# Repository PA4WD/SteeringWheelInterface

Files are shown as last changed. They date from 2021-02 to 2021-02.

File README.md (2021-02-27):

Steering wheel interface for Nissan Note 2006  to Kenwood NEC remote input

orginal wiring  in the car

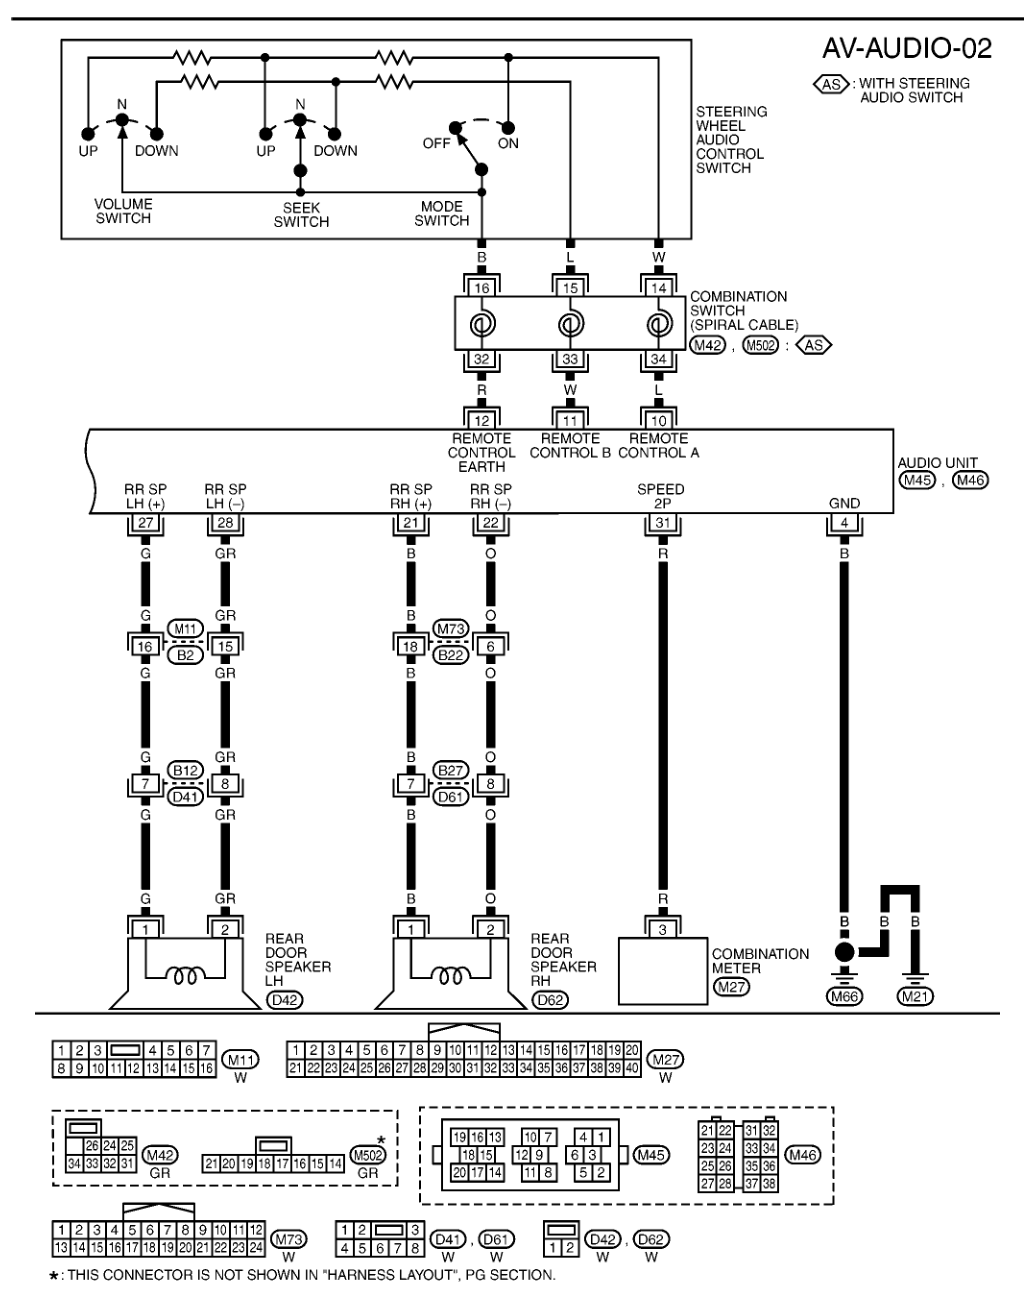
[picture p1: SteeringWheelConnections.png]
Steering wheel to radio


Resistor values from the steering wheel buttons

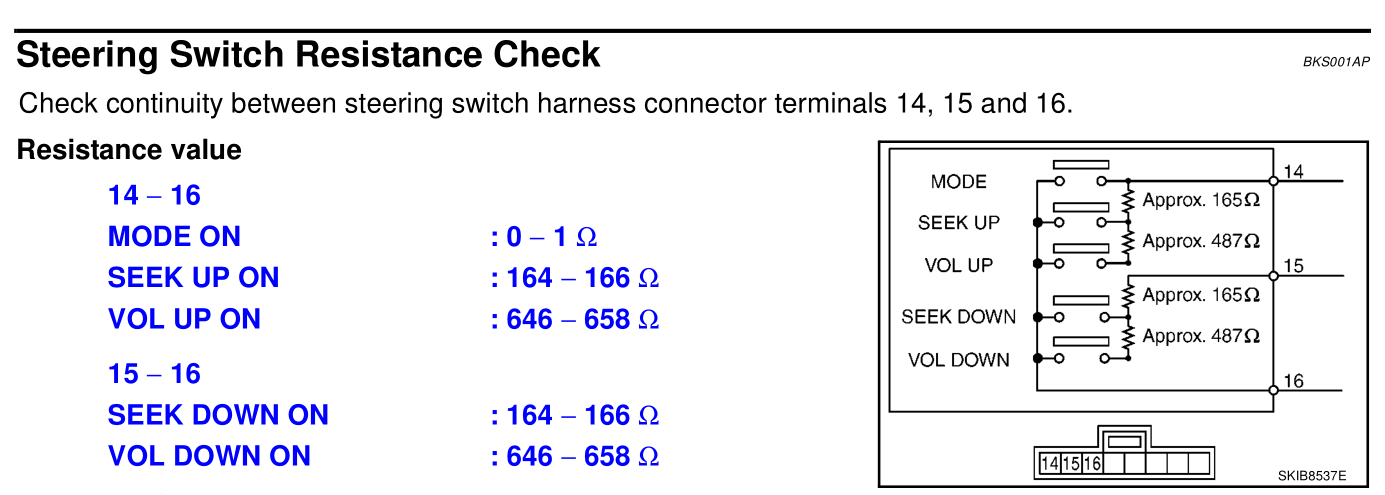
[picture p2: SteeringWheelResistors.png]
Steering wheel resistor values


Connect info button \n radio connector to ground.

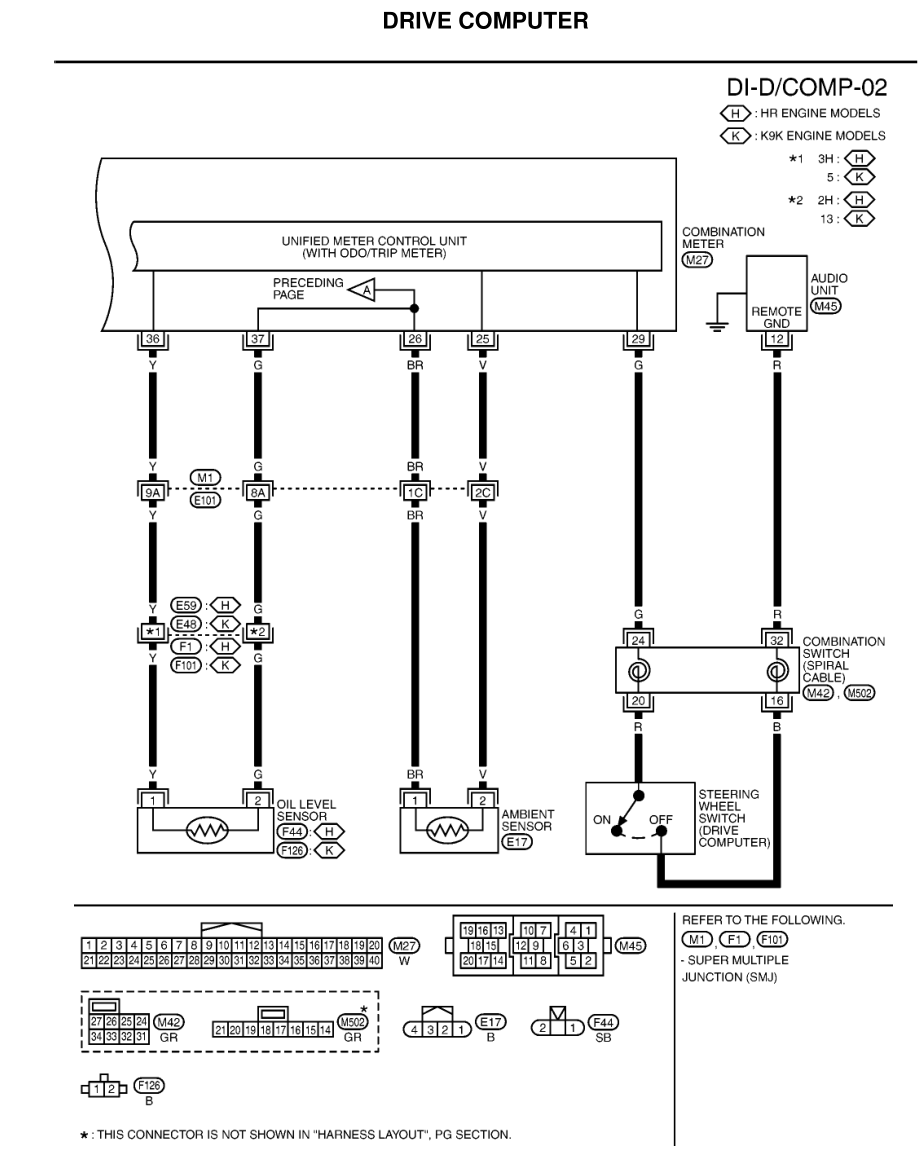
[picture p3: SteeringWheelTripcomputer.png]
Info button


NEC Radio codes for the Kenwood

| meaning | code |
|---|---|
| tuner | 0xb91c |
| tape | 0xb91d |
| cd | 0xb91e |
| cd-md-ch | 0xb91f |
| track- | 0xb90a |
| track+ | 0xb90b |
| rew | 0xb90c |
| ff | 0xb90d |
| dnpp (?) | 0xb95e |
| play/pause | 0xb90e |
| --- | |
| volume+ | 0xb914 |
| volume- | 0xb915 |
| source | 0xb913 |
| mute | 0xb916 |
| --- | |
| 0 | 0xb900 |
| 1 | 0xb901 |
| 2 | 0xb902 |
| 3 | 0xb903 |
| 4 | 0xb904 |
| 5 | 0xb905 |
| 6 | 0xb906 |
| 7 | 0xb907 |
| 8 | 0xb908 |
| 9 | 0xb909 |

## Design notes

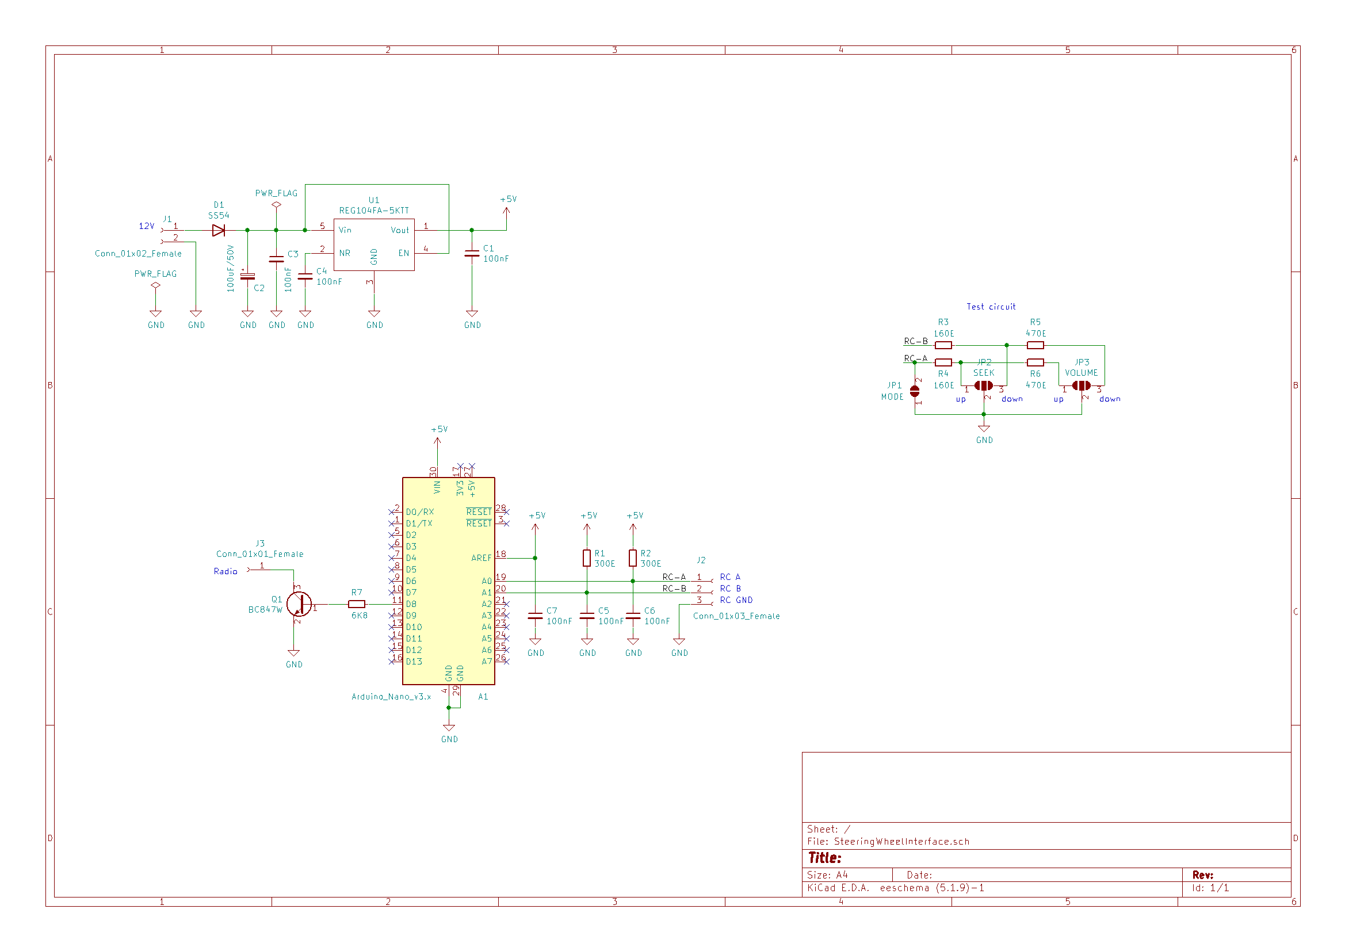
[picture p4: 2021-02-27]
SteeringWheelInterface/Schematic.png

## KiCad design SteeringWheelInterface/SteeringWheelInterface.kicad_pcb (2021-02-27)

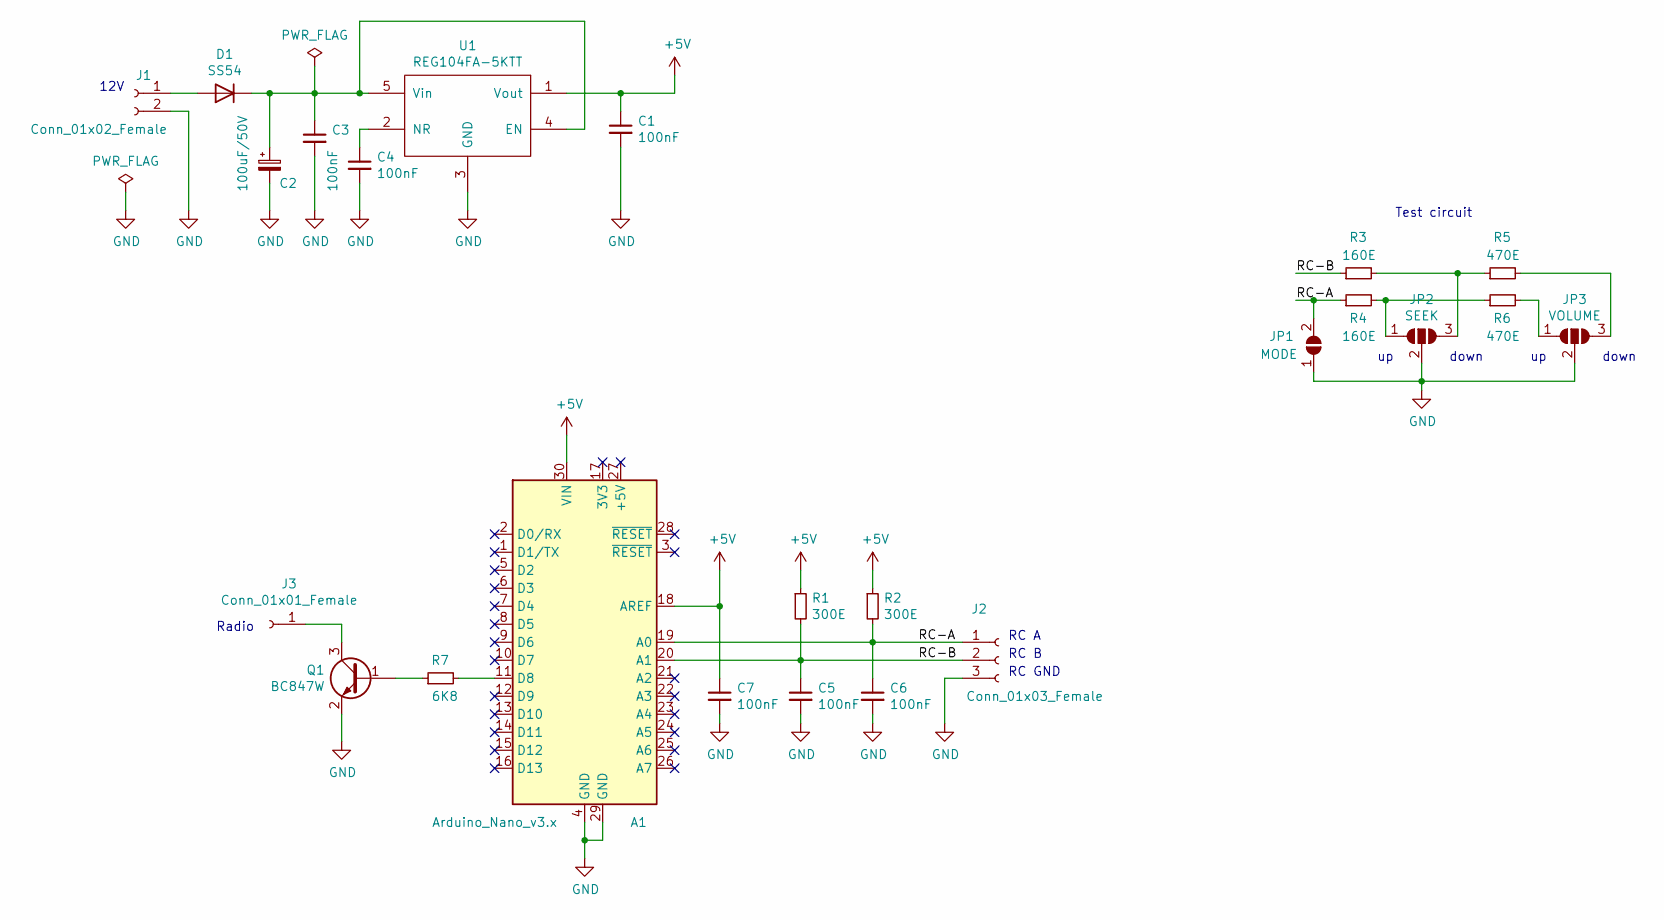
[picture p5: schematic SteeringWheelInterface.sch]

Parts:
A1: Arduino_Nano_v3.x; Arduino_Nano
C1, C3, C4, C5, C6, C7: 100nF; C_1206_3216Metric_Pad1.42x1.75mm_HandSolder
C2: 100uF/50V; CP_Radial_D8.0mm_P3.80mm
D1: SS54; D_2114_3652Metric_Pad1.85x3.75mm_HandSolder
J1: Conn_01x02_Female; PinHeader_1x02_P2.54mm_Vertical
J2: Conn_01x03_Female; PinHeader_1x03_P2.54mm_Vertical
J3: Conn_01x01_Female; PinHeader_1x01_P2.54mm_Vertical
JP1: MODE; SolderJumper-2_P1.3mm_Open_Pad1.0x1.5mm
JP2: SEEK; SolderJumper-3_P1.3mm_Open_Pad1.0x1.5mm
JP3: VOLUME; SolderJumper-3_P1.3mm_Open_Pad1.0x1.5mm
Q1: BC847W; SOT-323_SC-70
R1, R2: 300E; R_1206_3216Metric_Pad1.42x1.75mm_HandSolder
R3, R4: 160E; R_1206_3216Metric_Pad1.42x1.75mm_HandSolder
R5, R6: 470E; R_1206_3216Metric_Pad1.42x1.75mm_HandSolder
R7: 6K8; R_1206_3216Metric_Pad1.42x1.75mm_HandSolder
U1: REG104FA-5KTT; TO-263-5_TabPin3

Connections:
+5V: A1.18 (AREF), A1.30 (VIN), C1.1, C7.1, R1.1, R2.1, U1.1 (Vout)
/RC-A: A1.19 (A0), C6.1, J2.1, JP1.2 (B), R2.2, R4.1
/RC-B: A1.20 (A1), C5.1, J2.2, R1.2, R3.1
GND: A1.4 (GND), A1.29 (GND), C1.2, C2.2, C3.2, C4.2, C5.2, C6.2, C7.2, J1.2, J2.3, JP1.1 (A), JP2.2 (C), JP3.2 (C), Q1.2 (E), U1.3 (GND)
unnamed: A1.11 (D8), R7.2
unnamed: C2.1, C3.1, D1.1 (K), U1.4 (EN), U1.5 (Vin)
unnamed: C4.1, U1.2 (NR)
unnamed: D1.2 (A), J1.1
unnamed: J3.1, Q1.3 (C)
unnamed: JP2.1 (A), R4.2, R6.1
unnamed: JP2.3 (B), R3.2, R5.1
unnamed: JP3.1 (A), R6.2
unnamed: JP3.3 (B), R5.2
unnamed: Q1.1 (B), R7.1

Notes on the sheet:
12V
RC A
RC B
RC GND
Radio
down
Test circuit

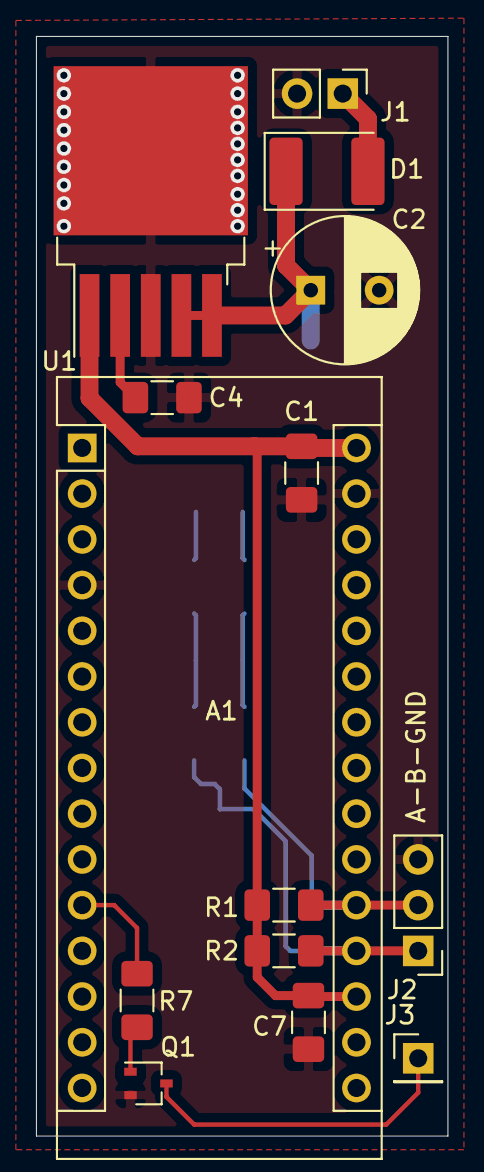
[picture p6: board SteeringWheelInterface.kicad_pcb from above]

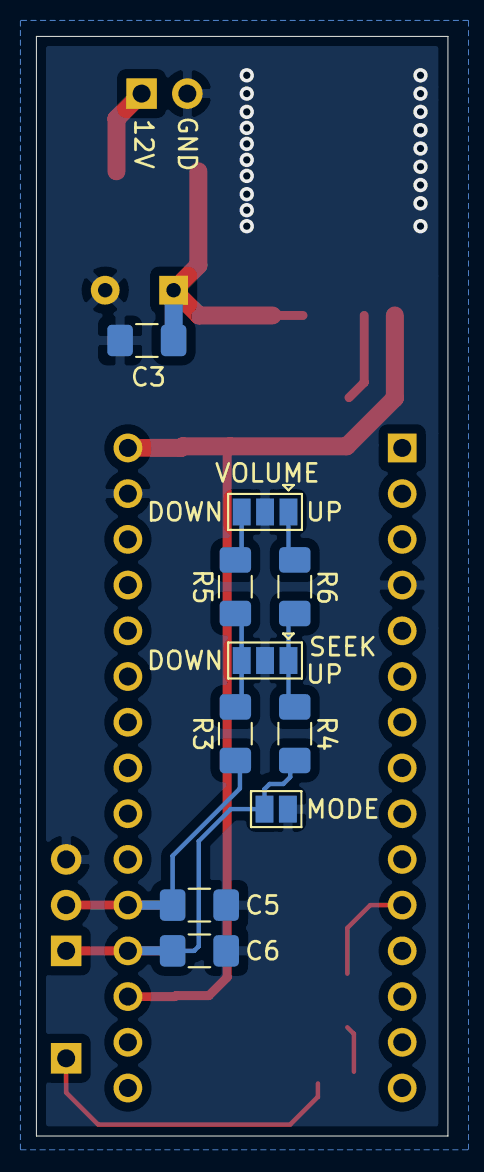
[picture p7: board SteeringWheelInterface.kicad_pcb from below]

Board: 2 copper layers, 22.9 x 61.1 mm, 24 parts (10 on the bottom side), 14 nets.

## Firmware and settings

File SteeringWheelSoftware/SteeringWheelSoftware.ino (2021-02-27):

#include "Average.h" //https://github.com/MajenkoLibraries/Average

#define OUTPUT_RADIO      PB0
#define INPUT_A           A0
#define INPUT_B           A1

#define ONE_TIME          2250UL
#define ZERO_TIME         1120UL
#define REPEAT_TIME       110000UL

#define KENWOOD_ADDRESS   0xb9
#define KENWOOD_SEEK_DOWN 0x0a
#define KENWOOD_SEEK_UP   0x0b
#define KENWOOD_SOURCE    0x13
#define KENWOOD_VOL_UP    0x14
#define KENWOOD_VOL_DOWN  0x15
#define KENWOOD_MUTE      0x16

#define ANALOG_SAMPLES    10

Average<int> analog_average(ANALOG_SAMPLES);

static inline void on() {
  PORTB |= _BV(OUTPUT_RADIO);
}
static inline void off() {
  PORTB &= ~_BV(OUTPUT_RADIO);
}

static void send_leader() {
  on();
  _delay_us(9000);
  off();
  _delay_us(4500);
}
static void send_1() {
  on();
  _delay_us(560);
  off();
  _delay_us(ONE_TIME - 560);
}
static void send_0() {
  on();
  _delay_us(560);
  off();
  _delay_us(ZERO_TIME - 560);
}

static void send_byte(byte val) {
  for (int y = 0; y < 8; y++) { // Iterate though every bit
    if ( val >> y & 0b00000001 ) {
      send_1();
    } else {
      send_0();
    }
  }
}

static void send_key(byte key) {
  send_leader();
  send_byte(KENWOOD_ADDRESS); //normal
  send_byte(~(KENWOOD_ADDRESS)); //invert
  send_byte(key); //normal
  send_byte(~key); //invert
  send_1(); //end transmission
  _delay_us(REPEAT_TIME - 16 * ZERO_TIME - 16 * ONE_TIME); //pause for next transmission
}

int sampleAnalogInput(int input) {
  for (int i = 0; i < ANALOG_SAMPLES; i++) {
    analog_average.push(analogRead(input));
    _delay_us(100);
  }

  // Display the current data set
  //  for (int i = 0; i < ANALOG_SAMPLES; i++) {
  //    Serial.print(analog_average.get(i));
  //    Serial.print(" ");
  //  }
  //  Serial.println();

  return analog_average.mode();
}



void setup() {
  pinMode(LED_BUILTIN, OUTPUT);
  pinMode(OUTPUT_RADIO, OUTPUT);
  Serial.begin(115200);

  Serial.println(F("Ready to send IR signals at pin "));
}

void loop() {
  int rcA = sampleAnalogInput(INPUT_A);
  int rcB = sampleAnalogInput(INPUT_B);
  //Serial.println(rcA);
  //Serial.println(rcB);

  if (rcA < 1000) {
    //Serial.print("rcA ");
    Serial.println(rcA);
    if (rcA < 50) { //Mode button
      send_key(KENWOOD_SOURCE);
      Serial.println(F("Source"));
      delay(1000);
    }
    if (rcA > 300 && rcA < 400) {
      send_key(KENWOOD_SEEK_UP);
      Serial.println(F("Seek up"));
      delay(1000);
    }
    if (rcA > 650 && rcA < 750) {
      send_key(KENWOOD_VOL_UP);
      Serial.println(F("Volume up"));
      delay(1000);
    }
  }
  if (rcB < 1000) {
    //Serial.print("rcB ");
    Serial.println(rcB);
    if (rcB > 300 && rcB < 400) {
      send_key(KENWOOD_SEEK_DOWN);
      Serial.println(F("Seek down"));
      delay(1000);
    }
    if (rcB > 650 && rcB < 750) {
      send_key(KENWOOD_VOL_DOWN);
      Serial.println(F("Volume down"));
      delay(1000);
    }
  }


  //delay(5000);

  while (Serial.available() > 0) {
    char chr = Serial.read();
    if (chr == '+') {
      send_key(KENWOOD_VOL_UP);
      //Serial.println(F("Volume up"));
    }
    if (chr == '-') {
      send_key(KENWOOD_VOL_DOWN);
      //Serial.println(F("Volume down"));
    }
    if (chr == 's') {
      send_key(KENWOOD_SOURCE);
      //Serial.println(F("source"));
    }
    if (chr == 'u') {
      send_key(KENWOOD_SEEK_UP);
      //Serial.println(F("Seek up"));
    }
    if (chr == 'd') {
      send_key(KENWOOD_SEEK_DOWN);
      //Serial.println(F("Seek down"));
    }
  }
}
